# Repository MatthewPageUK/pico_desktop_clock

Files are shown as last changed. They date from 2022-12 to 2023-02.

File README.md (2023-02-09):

# Raspberry Pi Pico Desktop Clock with Round LCD

A little desktop clock with round display for Raspberry Pi Pico, or could be coded to do and be anything you want.

* Acquires current time from NTP
* Customisable alarms with snooze feature
* Buzzer to play musical alarms

### Latest
* 9 Feb 2023 - Added boot script to record last known time, update the buzzer and musical tones
* 21 Jan 2023 - Version 2 - new design, added buttons, buzzer and alarms
* 20 Jan 2023 - Moved the star movement to core1, added simple alarms, a night mode ready for a light sensor, ASCII art and got the AI to write some comments for me.
* 30 Dec 2022 - Fixed some time and code issues

### Version 2
https://user-images.githubusercontent.com/46349796/213926866-4d1f6632-3ad6-42b0-ba31-92c4016c5022.mp4

### Hardare requirements:
* Raspberry Pi Pico-W
* 1.3" SPI Round LCD Screen (240x240)
* 2 x momentary push buttons (Omron type B3F with long extension)
* Buzzer

## Round LCD 1.3" SPI
https://thepihut.com/products/1-3-spi-colour-round-lcd-240x240-breakout

## Pico W
https://thepihut.com/products/raspberry-pi-pico-w

## LCD Wiring
* 3-5V to any 5V or 3V pin
* CS to GP17
* SCK to GP18
* MOSI to GP19
* DC to GP16
* BL to GP20
* GND to any ground pin

### Button Wiring
* Button 1 to GP0
* Button 2 to GP1
* GND to any ground pin (3)

### Buzzer Wiring
* Positive to GP15
* Negative to any ground pin (18)





## Python MModules
Installed MicroPython with Pimoroni graphics via Thonny

https://github.com/pimoroni/pimoroni-pico/tree/main/micropython/modules/picographics

## Printing
Printed on an Ender 3 Neo v2 with standard settings and PLA filament. (Nasty top layer)



Desktop Clock v2 v10

# Bugs
* Multicore seems to crash alot, especially with the IRQ buttons..
Freeware - use as you wish

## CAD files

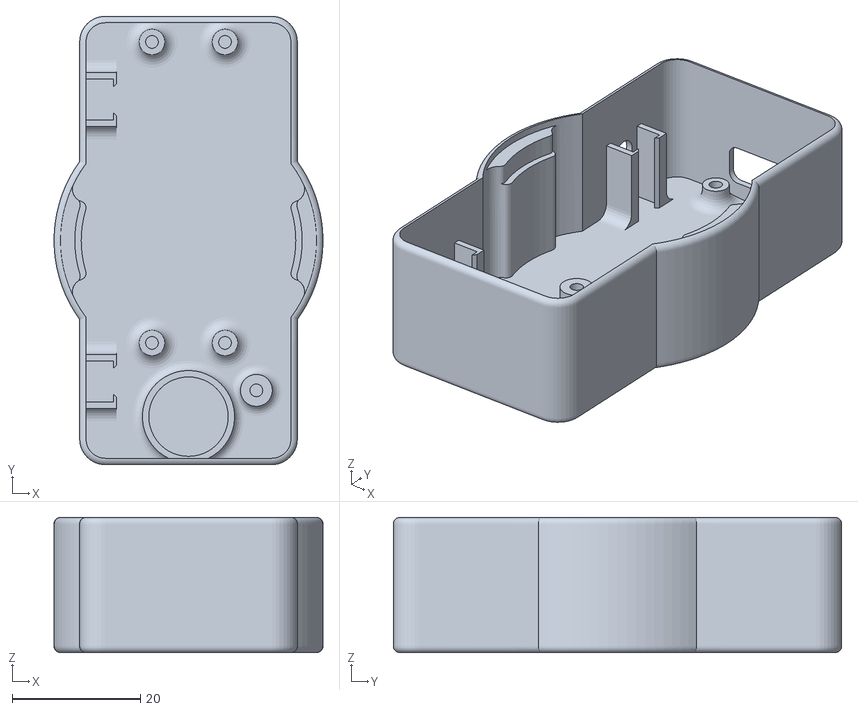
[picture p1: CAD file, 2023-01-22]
3dprint/DeskClock-v2-Base.stl
42.0 x 70.0 x 21.1

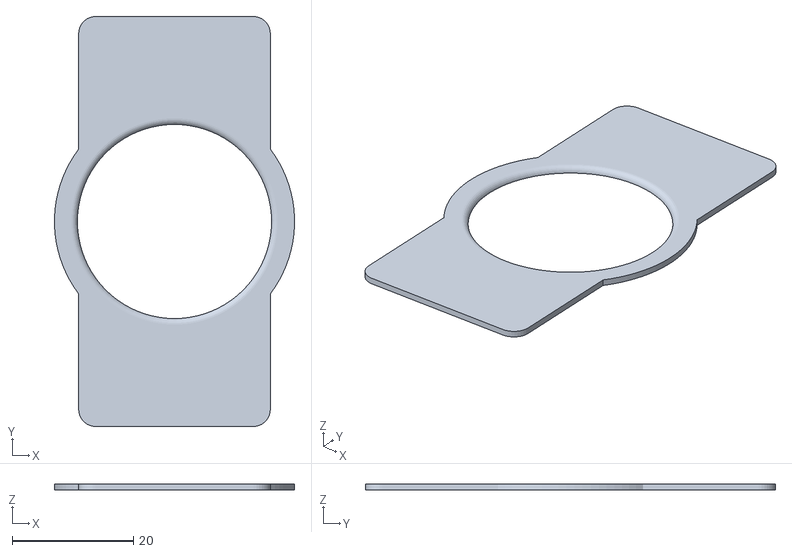
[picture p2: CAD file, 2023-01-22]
3dprint/DeskClock-v2-Top.stl
39.6 x 67.6 x 1.00

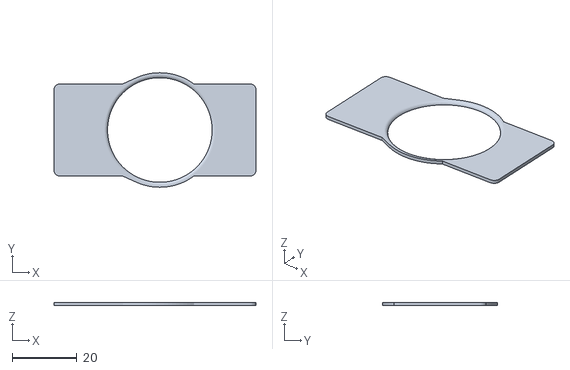
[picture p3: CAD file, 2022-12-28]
3dprint/PicoBoxLCDTop-v1.stl
62.6 x 35.5 x 1.00

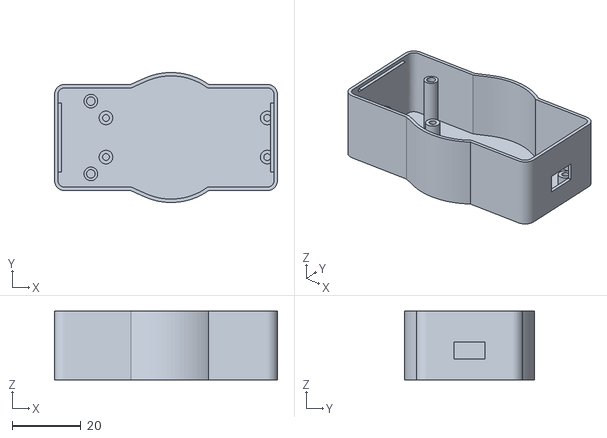
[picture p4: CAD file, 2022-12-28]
3dprint/PicoBoxLCDBase-v1.stl
65.0 x 37.9 x 20.0

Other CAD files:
fusion360/Desktop-Clock-v1-2022-12-22.f3z
fusion360/Desktop-Clock-v2-2023-01-22.f3z
fusion360/LCD Round 1.3_ SPI v1.f3d
fusion360/Pico W v1.f3d

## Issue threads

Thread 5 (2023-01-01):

Set time when offline

MatthewPageUK, 2023-01-01:
If we can't get a wifi connection need a way to set the time. A rotary dial on the back, use switches ...

samveen, 2023-01-29:
An additional suggestion is to save the clock to disk so that there is a saved time value to reuse on reset, like the fake-hwclock on `Raspbian`:

```
"""
A boot.py that does time saving and restoring if a save is available.
"""
import ustruct
r=machine.RTC()

# Restore clock save or set sane default value if no save
try:
    with open("hwclock.save","rb") as fr: r.datetime(ustruct.unpack("<8I",fr.read()))
except OSError as e:
    r.datetime((2023, 1, 29, 6, 13, 55, 0, 0))

def rtSaverCallback(t):
    with open("hwclock.save","w") as fw: fw.write(ustruct.pack("<8I",*(r.datetime())))

# periodic firing of the function every 1000ms (longer or shorter as required)
rtsaver = machine.Timer(mode=machine.Timer.PERIODIC, period=1000, callback=rtSaverCallback)
```

MatthewPageUK, 2023-01-31:
Thanks @samveen , that's a neat little idea.

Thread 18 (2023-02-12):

Rotary encoder dial on back

MatthewPageUK, 2023-02-12:
Have a rotary dial on the back which can be used to set the time and maybe scroll through other features or settings.

Looking at using this
https://thepihut.com/products/ano-directional-navigation-and-scroll-wheel-rotary-encoder

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

Fit is going to be tight and may need re-wiring the Pico from below.

MatthewPageUK, 2023-02-12:
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

samveen, 2023-02-13:
A couple of observations about options:

Option 1 - use  an El Cheapo encoder (following the usage pattern for El Cheapo children's watches)  that just senses rotation:
   - Long press of one Button1/Button2 enters modification mode
   - In modification mode, quick press of buttons cycle through modifiable selections
   - Rotation always increments, and loops back to minimum at maximum
    - Pros: Minimal/cheap hardware, just one extra hole in the case
    - Cons: Lots of hoops to jump though in software, the repetitions in this usage pattern get old really quick.

Option 2 - Bells and whistles encoder
    - Ease of use
    - Non-repetitive usage pattern
    -  Pros: Quicker usage
    - Cons: Not as easily accessible hardware, lots of extra wiring and design considerations.

MatthewPageUK, 2023-02-13:
I agree with all your points there. I really like the Bells and Whistles encoder, feels nice, same diameter as the LCD, but it is a bit of work to redesign the case etc.

Good point about it not being easily accessible hardware. Should try to keep it to simple parts that could be swapped with something similar if you can't get the exact one.

Most of the other encoders are very big, but I have just found **mouse wheel encoders**

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

https://uk.rs-online.com/web/p/mechanical-rotary-encoders/7295536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

Small, easily available and could be swapped out for a different encoder if you can't get the exact model.

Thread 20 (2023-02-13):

Button clips don't work well, needs re-designing

MatthewPageUK, 2023-02-13:
The button should clip into the base, but also needs to be fixed well so they don't pop out when pressed. Temp fix is glue, but I don't want any glued in parts.

Maybe a screw fixing or bracket..

samveen, 2023-04-17:
Also please consider flipping the Pico to expose the bootsel button, as the latest nightly builds of micropython allow the bootsel buttonto be used as user input button, (via https://github.com/micropython/micropython/pull/10935). This reduces the BOM by one button, and it's associated wiring.

An example of such usage can be found at https://github.com/samveen/pico-mpy-2fa-totp/blob/main/password.py#L26

MatthewPageUK, 2023-04-22:
>

Thanks @samveen , that's a really useful feature. I've been working with some 3d printed buttons, this will work well with it..

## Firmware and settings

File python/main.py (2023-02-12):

"""
  ____            _    _                 ____ _            _
 |  _ \  ___  ___| | _| |_ ___  _ __    / ___| | ___   ___| | __
 | | | |/ _ \/ __| |/ / __/ _ \| '_ \  | |   | |/ _ \ / __| |/ /
 | |_| |  __/\__ \   <| || (_) | |_) | | |___| | (_) | (__|   <
 |____/ \___||___/_|\_\\__\___/| .__/   \____|_|\___/ \___|_|\_\
                               |_|

 Raspberry Pi Pico-W desktop clock

 Displays a clock on the LCD screen with an animated starfield background
 Connects to a WiFi network to get the time from an NTP server
 Displays alarms and notifications at set times
 Plays musical alarms
 Snooze feature (coming soon)

 Firmware requirements:
    Micropython with Pimoroni Picographics library

 Hardare requirements:
    Raspberry Pi Pico-W
    1.3" SPI Round LCD Screen (240x240)
    2 x momentary push buttons (Omron type B3F with long extension)
    1 x buzzer

 Default screen wiring:
    CS to GP17
    SCK to GP18
    MOSI to GP19
    DC to GP16
    BL to GP20

 Button Wiring
    Button 1 to GP0
    Button 2 to GP1
    GND to any ground pin (3)

 Buzzer Wiring
    Positive to GP15
    Negative to any ground pin (18)

 By           - Matthew Page
 Credit       - Everyone who came before and wrote a how to guide
 Version      - 0.3
 Release date - 9th Febuary 2023
"""
import math
import random
import utime
import network
import ntptime
import _thread
from machine import Pin, PWM
from picographics import PicoGraphics, DISPLAY_ROUND_LCD_240X240, PEN_P8
from buzzer import Buzzer

display = PicoGraphics(display=DISPLAY_ROUND_LCD_240X240, pen_type=PEN_P8, rotate=90)

# General settings and constant(ishes)
NTP = True                          # Enable NTP time sync
WIFI_SSID = "network"               # WiFi network name
WIFI_PASSWORD = "password"          # WiFi network password
THEME = "RED"                       # Filament colour used to print the case
MULTICORE = True                    # Enable multicore - sometimes buggy
NIGHT_MODE = False                  # Default to day mode
WIDTH = display.get_bounds()[0]     # Screen width
HEIGHT = display.get_bounds()[1]    # Screen height
MIDX = int(WIDTH/2)                 # Middle of the screen
MIDY = int(WIDTH/2)                 # Middle of the screen
FPS = 25                            # Target frame rate
if THEME == "PURPLE":               # Purple case
    PURPLE = display.create_pen(255, 50, 255)
elif THEME == "RED":                # Red case
    PURPLE = display.create_pen(255, 50, 50)
BG = display.create_pen(90, 25, 70)
GREEN = display.create_pen(50, 255, 50)
BLACK = display.create_pen(0, 0, 0)
STARS_COLOUR = display.create_pen(220, 200, 220)
STARS_TOTAL = 200                   # Number of stars to show
STARS_SPEED_MAX = 25                # Max speed of stars
DEFAULT_NOTIFICATION_DELAY = 2      # Time notifications are displayed for
BUZZER_PIN = 15                     # Buzzer GPIO pin
BUTTON1_PIN = 0                     # Button 1 GPIO pin
BUTTON2_PIN = 1                     # Button 2 GPIO pin

def notification(text, colour, delay = DEFAULT_NOTIFICATION_DELAY, background = BG):
    """Show a notification on the display
    text: The text to show
    colour: The colour of the text
    delay: The delay in seconds before clearing the screen
    background: The background colour"""
    display.set_pen(background)
    display.clear()
    display.set_pen(colour)
    display.text(text, int((WIDTH - display.measure_text(text, 2)) / 2), 110, 200, 2)
    display.update()
    utime.sleep(delay)

def showAlarm(text):
    """Show an alarm message on the display and play a song while the alarm is active
    text: The text to show"""
    global alarmActive

    if not alarmActive:
        alarmActive = True
        while alarmActive:
            if alarmActive:
                notification(text, PURPLE, 0.5)
            if alarmActive:
                buzzer.playSong()
            if alarmActive:
                notification(text, BG, 0.5, PURPLE)

def setNtpTime(ssid, password):
    """Connect to the WIFI and get the time from NTP
    ssid: The WIFI SSID
    password: The WIFI password"""

    notification("Setting time...", GREEN)

    # Connect to WIFI
    wifiNetwork = network.WLAN(network.STA_IF)
    wifiNetwork.active(True)
    wifiNetwork.connect(ssid, password)

    notification("Connecting to WIFI...", GREEN)
    wifiCount = 1

    # Wait for connection
    while wifiNetwork.status() != network.STAT_GOT_IP:
        notification("Connecting... {c}".format(c=wifiCount), GREEN, 1)
        wifiCount += 1

    # Get time from NTP
    notification("Getting NTP time", GREEN)
    ntptime.settime()

    # Disconnect from WIFI
    wifiNetwork.disconnect()
    wifiNetwork.active(False)
    notification("Done", PURPLE)

    return True

def drawRing(value, distance, intervals = 60, small = 3, large = 6, inner = 1):
    """Draw an outer ring on the clock face
    value: The value to show
    distance: The distance from the centre
    intervals: The number of intervals
    small: The size of the small dots
    large: The size of the large dots
    inner: The size of the inner dot circle"""

    for dot in range(0, intervals):

        # Calculate the position of the dot
        angle = math.pi * 2 * (dot / intervals) - math.pi / 2
        x = int(MIDX + math.cos(angle) * distance)
        y = int(MIDY + math.sin(angle) * distance)

        # Set the colour and radius of the dot
        if dot >= value:
            colour = GREEN
        else:
            colour = PURPLE

        if dot == value:
            radius = large
        else:
            radius = small

        # Draw the dot
        display.set_pen(colour)
        display.circle(x, y, radius)
        display.set_pen(BG)
        display.circle(x, y, inner)

def drawHand(value, distance, intervals = 60):
    """Draw a hand on the clock face
    value: The hand position
    distance: The distance from the centre
    intervals: The number of intervals"""

    display.set_pen(GREEN)

    # Calculate the position of the hand
    angle = math.pi * 2 * (value / intervals) - math.pi / 2
    x = int(MIDX + math.cos(angle) * distance)
    y = int(MIDY + math.sin(angle) * distance)

    # Draw the hand
    display.line(MIDX, MIDY, x, y)

class Star:
    """A star class
    x: The x position
    y: The y position
    r: The radius
    dx: The x velocity
    dy: The y velocity"""

    def __init__(self, x = MIDX, y = MIDY, r = 1, dx = 0, dy = 0):
        self.x = x
        self.y = y
        self.r = r
        self.dx = dx
        self.dy = dy
        self.rebirth()

    def move(self):
        """Move the star and rebirth if off screen"""

        # Increase the speed of the stars as the clock ticks
        speed = 15 - (clock_seconds % 60) // 4
        self.x += self.dx / speed
        self.y += self.dy / speed
        if self.x < 0 or self.x > WIDTH or self.y < 0 or self.y > HEIGHT:
            self.rebirth()

    def draw(self):
        """Draw the star on the display"""
        display.set_pen(STARS_COLOUR)
        display.circle(int(self.x), int(self.y), int(self.r))

    def rebirth(self):
        """Rebirth the star in the middle with random vector"""
        self.x = MIDX
        self.y = MIDY
        self.dx = random.randint(0, STARS_SPEED_MAX * 2) - STARS_SPEED_MAX
        self.dy = random.randint(0, STARS_SPEED_MAX * 2) - STARS_SPEED_MAX

def moveStars():
    """Move the stars in a loop - runs as process in core 1 """
    global restartCore1, messages
    try:
        restartCore1 = False
        while True:
            for star in stars:
                star.move()
            utime.sleep(1 / FPS)
    # Sometimes a thread is left running, so catch the error and restart
    # Only happens when you're stopping and starting the program
    except Exception as e:
        messages.append("Restaring core1: {e}".format(e=e))
        restartCore1 = True
        _thread.exit()

def button1Handler(pin):
    """Button 1 IRQ handler - cancels the alarm or toggles Night Mode"""
    global alarmActive, NIGHT_MODE, button1Debounce, seconds, buzzer, messages

    # Check the time the button was last pressed, debounce
    if button1Debounce == 0 or seconds - button1Debounce > 1:
        button1Debounce = seconds

        if alarmActive:
            alarmActive = False
            messages.append("Alarm cancelled")
        else:
            buzzer.yes()
            NIGHT_MODE = not NIGHT_MODE

def button2Handler(pin):
    """Button 2 IRQ handler - snoozes the alarm"""
    global alarmActive, button2Debounce, seconds, messages

    # Check the time the button was last pressed, debounce
    if button2Debounce == 0 or seconds - button2Debounce > 1:
        button2Debounce = seconds

        alarmActive = False
        buzzer.no()
        messages.append("Snoozed")

# Message queue buffer
messages=[]

# Debounce the IRQ buttons, this stores the last time they were pressed
button1Debounce = 0
button2Debounce = 0

# Main Program
restartCore1 = MULTICORE
notification("Starting up!", PURPLE)

# Setup the buttons
button1 = Pin(BUTTON1_PIN, Pin.IN, Pin.PULL_UP)
button2 = Pin(BUTTON2_PIN, Pin.IN, Pin.PULL_UP)

# Setup button 1 and 2 with and IRQ handler
# This is all very buggy and results in random freezes
button1.irq(trigger=Pin.IRQ_FALLING, handler=button1Handler)
button2.irq(trigger=Pin.IRQ_FALLING, handler=button2Handler)

# Set up the buzzer
buzzer = Buzzer(BUZZER_PIN)

# Default alarms (Hours, Minutes, Seconds, Message)
alarms = ((8, 30, 0, "Time to get up!"), (12, 0, 0, "Lunch time!"), (17, 30, 0, "Time to go home!"), (21, 10, 0, "Time to go to bed!"))
alarmActive = False

# Get the time from NTP
if NTP:
    setNtpTime(WIFI_SSID, WIFI_PASSWORD)

# Create some stars
stars = []
for i in range(0, STARS_TOTAL):
    stars.append(Star())

startTime = utime.time()

# Main Loop
while True:

    # Log messages to console
    while len(messages):
        print(messages.pop(0))

    # Time in seconds
    seconds = utime.time()

    # Dim the display if in night mode - this could be triggered by a light sensor
    if NIGHT_MODE:
        display.set_backlight(0.3)
    else:
        display.set_backlight(1.0)

    # If we need to start / restart core1 thread, do it, but wait a sec for the thread to die
    if MULTICORE and restartCore1:
        utime.sleep(0.5)
        try:
            # Move the stars in core1 with a new thread
            core1 = _thread.start_new_thread(moveStars, ())
        except Exception as e:
            messages.append("core1 failed: {e}".format(e=e))

    # Show a test alarm 5 seconds after startup
    if seconds - startTime == 5:
        showAlarm("This is an alarm!")

    # Clock seconds, minutes and hours
    clock_seconds = seconds % (24 * 3600)
    clock_hours24 = clock_seconds // 3600
    clock_seconds %= 3600
    clock_minutes = clock_seconds // 60
    clock_seconds %= 60
    if clock_hours24 > 12:
        clock_hours = clock_hours24 - 12
    else:
        clock_hours = clock_hours24

    # Check for alarms
    for alarm in alarms:
        if alarm == (clock_hours24, clock_minutes, clock_seconds, alarm[3]):
            showAlarm(alarm[3])

    # Clear the screen
    display.set_pen(BG)
    display.clear()

    # Draw the stars that have been moved in core1, or move them if not using multicore
    for star in stars:
        if not MULTICORE:
            star.move()
        star.draw()

    # Draw the rings
    drawRing(clock_hours, 70, intervals = 12, small = 6, large = 8, inner = 2)
    drawRing(clock_minutes, 85)
    drawRing(clock_seconds, 100)

    # Draw the hands
    drawHand(clock_seconds, 90)
    drawHand(clock_minutes, 75)
    drawHand(clock_hours, 60, 12)

    # Draw the black hole
    display.set_pen(BLACK)
    display.circle(120, 120, 10)

    # Draw the time in a box
    display.set_pen(GREEN)
    text = "{clock_hours:d}:{clock_minutes:02d}:{clock_seconds:02d}".format(clock_hours=clock_hours, clock_minutes=clock_minutes, clock_seconds=clock_seconds)
    twidth = display.measure_text(text, 2)
    xpos = int((WIDTH - twidth) / 2)

    display.set_pen(BG)
    display.rectangle(xpos - 2, 85 - 2, twidth + 4, 20)

    display.set_pen(GREEN)
    display.text(text, xpos, 85, 0, 2)

    # Update the display
    display.update()

    # Sleep a while
    utime.sleep(1 / FPS)

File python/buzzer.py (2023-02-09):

"""
  ____            _    _                 ____ _            _
 |  _ \  ___  ___| | _| |_ ___  _ __    / ___| | ___   ___| | __
 | | | |/ _ \/ __| |/ / __/ _ \| '_ \  | |   | |/ _ \ / __| |/ /
 | |_| |  __/\__ \   <| || (_) | |_) | | |___| | (_) | (__|   <
 |____/ \___||___/_|\_\\__\___/| .__/   \____|_|\___/ \___|_|\_\
                               |_|

 Raspberry Pi Pico-W desktop clock

 Buzzer and musical tones

 Inspired by https://www.tomshardware.com/how-to/buzzer-music-raspberry-pi-pico

"""
from machine import Pin, PWM
from utime import sleep

"""Note lengths in beats
SB - Semibreve (whole note)
M - Minim (half note)
C - Crotchet (quarter note)
Q - Quaver (eighth note)
SQ - Semi-quaver (sixteenth note)
"""
NOTE_SB = 4
NOTE_M = 2
NOTE_C = 1
NOTE_Q = 0.5
NOTE_SQ = 0.25

# Musical tones in Hz
TONES = {
    "B0": 31, "C1": 33, "CS1": 35, "D1": 37, "DS1": 39, "E1": 41, "F1": 44, "FS1": 46, "G1": 49, "GS1": 52, "A1": 55, "AS1": 58, "B1": 62,
    "C2": 65, "CS2": 69, "D2": 73, "DS2": 78, "E2": 82, "F2": 87, "FS2": 93, "G2": 98, "GS2": 104, "A2": 110, "AS2": 117, "B2": 123,
    "C3": 131, "CS3": 139, "D3": 147, "DS3": 156, "E3": 165, "F3": 175, "FS3": 185, "G3": 196, "GS3": 208, "A3": 220, "AS3": 233, "B3": 247,
    "C4": 262, "CS4": 277, "D4": 294, "DS4": 311, "E4": 330, "F4": 349, "FS4": 370, "G4": 392, "GS4": 415, "A4": 440, "AS4": 466, "B4": 494,
    "C5": 523, "CS5": 554,"D5": 587, "DS5": 622, "E5": 659, "F5": 698, "FS5": 740, "G5": 784, "GS5": 831, "A5": 880, "AS5": 932, "B5": 988,
    "C6": 1047, "CS6": 1109, "D6": 1175, "DS6": 1245, "E6": 1319, "F6": 1397, "FS6": 1480, "G6": 1568, "GS6": 1661, "A6": 1760, "AS6": 1865, "B6": 1976,
    "C7": 2093, "CS7": 2217, "D7": 2349, "DS7": 2489, "E7": 2637, "F7": 2794, "FS7": 2960, "G7": 3136, "GS7": 3322, "A7": 3520, "AS7": 3729, "B7": 3951,
    "C8": 4186, "CS8": 4435, "D8": 4699, "DS8": 4978
}

# Beats per minute
BPM = 120

# Pause between notes
PAUSE = 0.01

"""Song to play - Happy Birthday"""
SONG = (
    ("C4", NOTE_Q), ("C4", NOTE_Q), ("D4", NOTE_C), ("C4", NOTE_C), ("F4", NOTE_C), ("E4", NOTE_M),
    ("C4", NOTE_Q), ("C4", NOTE_Q), ("D4", NOTE_C), ("C4", NOTE_C), ("G4", NOTE_C), ("F4", NOTE_M),
    ("C4", NOTE_Q), ("C4", NOTE_Q), ("C5", NOTE_C), ("A5", NOTE_C), ("F4", NOTE_C),
    ("E4", NOTE_C), ("D4", NOTE_C), ("B5", NOTE_Q), ("B5", NOTE_Q), ("A5", NOTE_C),
    ("F4", NOTE_C), ("G4", NOTE_C),  ("F4", NOTE_M)
)

class Buzzer():
    """Class to handle the buzzer.
    pin - The pin the buzzer is connected to"""
    def __init__(self, pin):
        self.pin = Pin(pin)
        self.pwm = PWM(self.pin)
        self.pwm.freq(500)
        self.pwm.duty_u16(0)

    def playNote(self, note):
        """Plays a note using the buzzer
        note - A tuple of the note to play and the length of the note"""
        if (note[0] == "R"):
            self.pwm.duty_u16(0)
        else:
            self.pwm.duty_u16(1000)
            self.pwm.freq(TONES[note[0]])

        sleep((60 / BPM) * note[1])
        self.pwm.duty_u16(0)
        sleep(PAUSE)

    def playSong(self):
        """Plays a song using the buzzer
        song - A tuple of notes to play"""
        for note in SONG:
            self.playNote(note)

        self.pwm.duty_u16(0)

    def alert(self):
        """Plays an alert sound using the buzzer"""
        self.pwm.duty_u16(1000)
        for x in range(500, 900, 3):
            self.pwm.freq(x)
            sleep(0.01)
        self.pwm.duty_u16(0)

    def beep(self):
        """Plays a beep sound using the buzzer"""
        self.playNote(("B5", NOTE_SQ))
        self.playNote(("D5", NOTE_SQ))

    def yes(self):
        """Plays a yes sound using the buzzer"""
        self.playNote(("C5", NOTE_SQ))

    def no(self):
        """Plays a no sound using the buzzer"""
        self.playNote(("E4", NOTE_SQ))
        self.playNote(("C4", NOTE_SQ))

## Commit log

2022-12-28 Version 1
    [LCD Round 1.3_ SPI v1.f3d, Pico Box - Round LCD v3.f3z, Pico W v1.f3d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]
2022-12-29 Code and time fixes - NTP and Wifi
    [main.py]
2023-01-20 Some additions and tweaks
    Moved the star movement to core1, added simple alarms, a night mode ready for a light sensor, ASCII art and got the AI to write some comments for me.
2023-01-22 Version 2
    [DeskClock-v2-Base.stl, DeskClock-v2-Top.stl, Desktop-Clock-v1-2022-12-22.f3z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]
2023-02-09 Handle exception caused by rare edge case of RTC save getting interrupted by power outage/cycle, and thus a corrupt save file
2023-02-09 Buzzing....
    #9 Updated the buzzer code
    [buzzer.py, main.py]
2023-02-12 Single point of logging, using a message buffer
    - Messages to be logged are queued into a message buffer.
    - Logging to console happens at a single point in the main loop.
    - Time sensitive components like IRQ handlers no longer touch slow
    tasks like IO.
    [main.py]
